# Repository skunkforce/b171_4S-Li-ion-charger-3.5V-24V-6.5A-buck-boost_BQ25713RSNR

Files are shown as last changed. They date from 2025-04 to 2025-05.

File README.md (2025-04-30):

# edgy_board number b171
This design is part of the [edgy board project](https://github.com/skunkforce/edgy_boards).



# getting started
This repository uses submodules. After cloning use the command 

```$ git submodule update --init --recursive```

to pull the submodules before opening the project with kicad. 

# Tests
Tests can be found in [TESTS.md](TESTS.md)

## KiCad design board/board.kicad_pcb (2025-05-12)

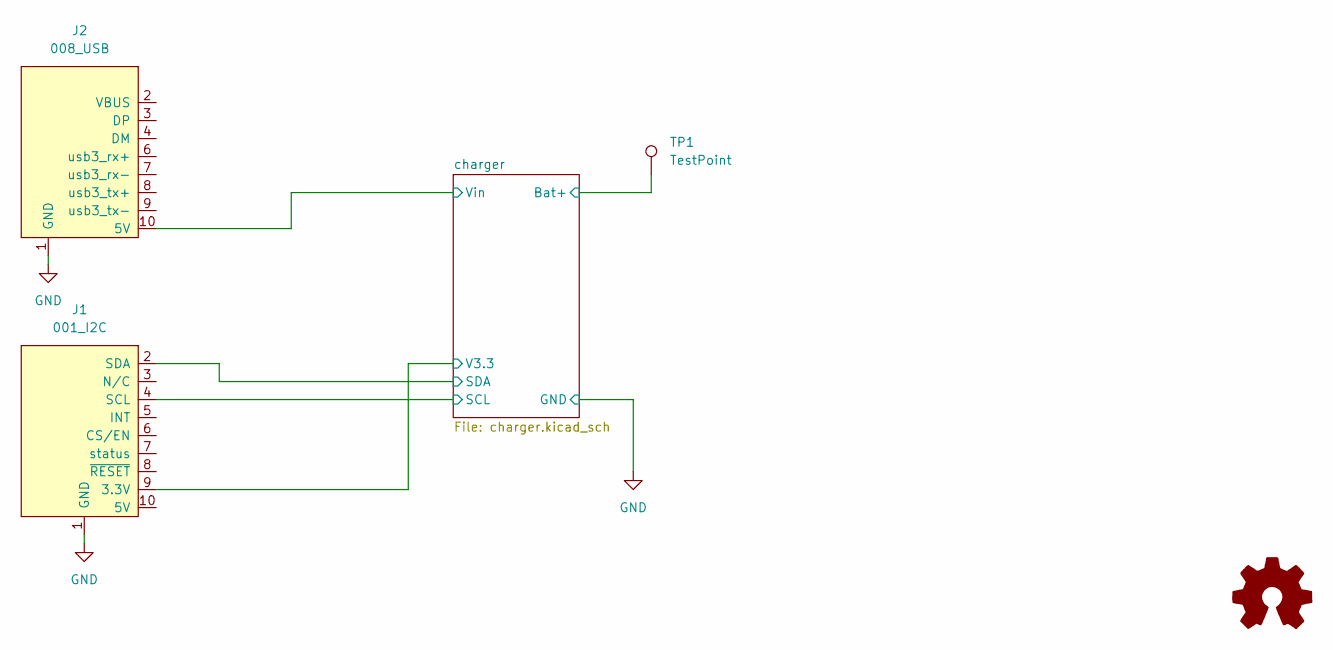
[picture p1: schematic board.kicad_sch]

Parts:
J1: 001_I2C; on_edge_2x05_device
J2: 008_USB; on_edge_2x05_device
LOGO1: Logo_Open_Hardware_Small; OSHW-Symbol_6.7x6mm_SilkScreen
TP1: TestPoint; TestPoint_Loop_D3.80mm_Drill2.8mm

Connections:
/charger/PACK+: TP1.1; also elsewhere on the board
/charger/SCL: J1.4 (SCL); also elsewhere on the board
/charger/SDA: J1.2 (SDA); also elsewhere on the board
/charger/V3.3: J1.9 (3.3V); also elsewhere on the board
/charger/VBUS: J2.10 (5V); also elsewhere on the board
GND: J1.1 (GND), J2.1 (GND); also elsewhere on the board

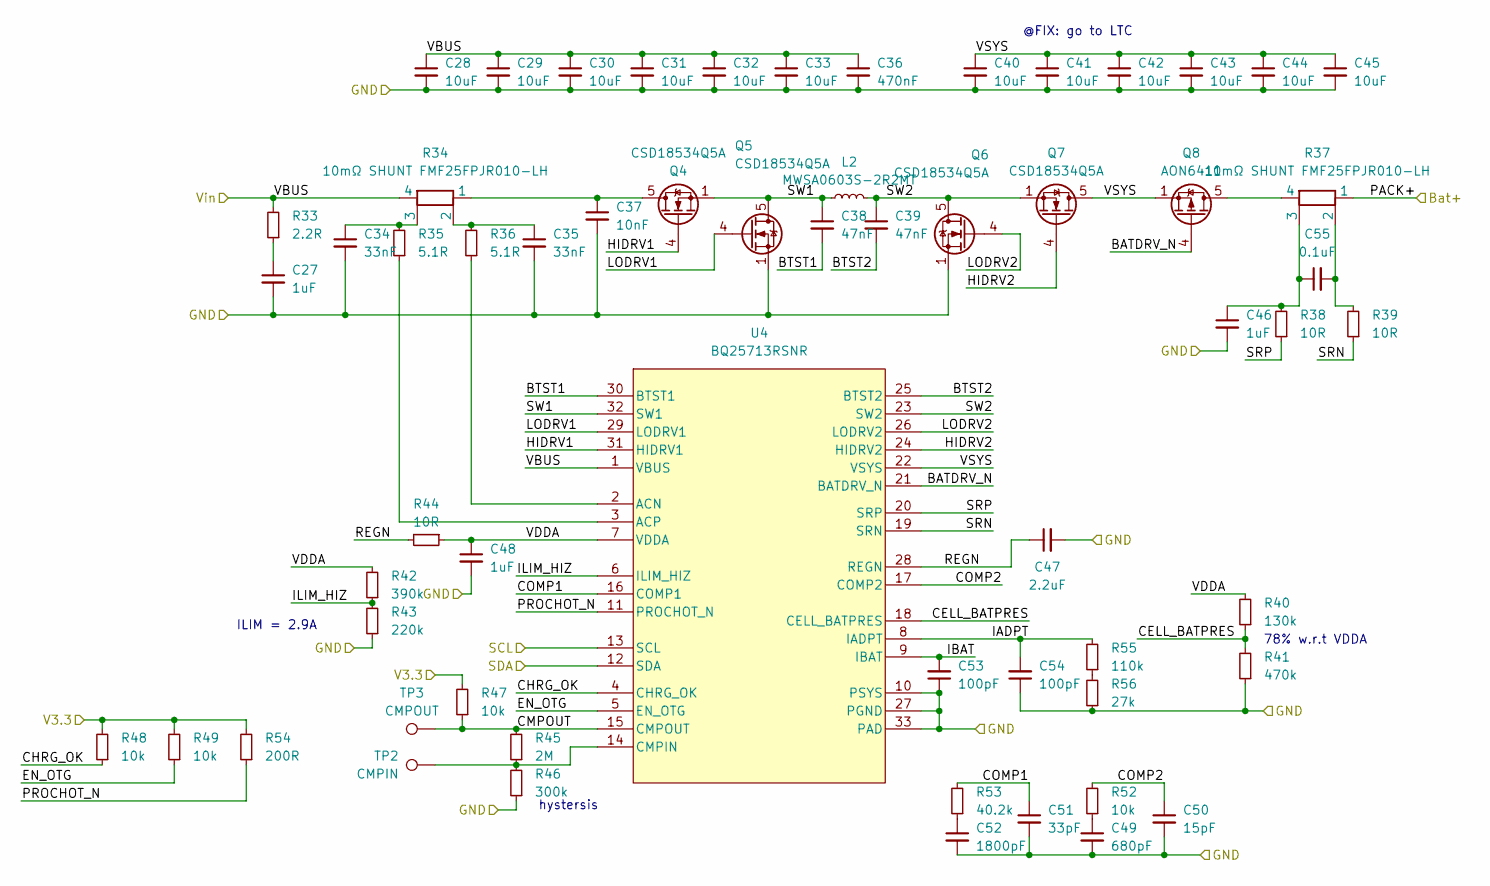
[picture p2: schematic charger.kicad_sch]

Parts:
C27, C46, C48: 1uF; C_0603_1608Metric; LCSC C15849
C28, C29, C30, C31, C32, C33, C40, C41, C42, C43, C44, C45: 10uF; C_0603_1608Metric; LCSC C96446
C34, C35: 33nF; C_0603_1608Metric; LCSC C21117
C36: 470nF; C_0603_1608Metric; LCSC C1623
C37: 10nF; C_0603_1608Metric; LCSC C57112
C38, C39: 47nF; C_0603_1608Metric; LCSC C1622
C47: 2.2uF; C_0603_1608Metric; LCSC C23630
C49: 680pF; C_0603_1608Metric; LCSC C1630
C50: 15pF; C_0603_1608Metric; LCSC C1644
C51: 33pF; C_0603_1608Metric; LCSC C1663
C52: 1800pF; C_0603_1608Metric; LCSC C1599
C53, C54: 100pF; C_0603_1608Metric; LCSC C14858
C55: 0.1uF; C_0603_1608Metric; LCSC C14663
L2: MWSA0603S-2R2MT; L_Sunlord_MWSA0603S; LCSC C408445
Q4, Q5, Q6, Q7: CSD18534Q5A; TDSON-8-1; LCSC C115943
Q8: AON6411; AO_DFN-8-1EP_5.55x5.2mm_P1.27mm_EP4.12x4.6mm
R33: 2.2R; R_0603_1608Metric; LCSC C22939
R34, R37: 10mΩ SHUNT FMF25FPJR010-LH; R_Shunt_Vishay_WSK2512_6332Metric_T1.19mm; LCSC C105366
R35, R36: 5.1R; R_0603_1608Metric; LCSC C25197
R38, R39, R44: 10R; R_0603_1608Metric; LCSC C22859
R40: 130k; R_0603_1608Metric; LCSC C22795
R41: 470k; R_0603_1608Metric; LCSC C23178
R42: 390k; R_0603_1608Metric; LCSC C23150
R43: 220k; R_0603_1608Metric; LCSC C22961
R45: 2M; R_0603_1608Metric; LCSC C22976
R46: 300k; R_0603_1608Metric; LCSC C23024
R47, R48, R49, R52: 10k; R_0603_1608Metric; LCSC C25804
R53: 40.2k; R_0603_1608Metric; LCSC C12447
R54: 200R; R_0603_1608Metric; LCSC C8218
R55: 110k; R_0603_1608Metric; LCSC C25805
R56: 27k; R_0603_1608Metric; LCSC C22967
TP2: CMPIN; TestPoint_Pad_2.0x2.0mm
TP3: CMPOUT; TestPoint_Pad_2.0x2.0mm
U4: BQ25713RSNR; Texas_RSN_WQFN-32-1EP_4x4mm_P0.4mm_EP2.8x2.8mm_ThermalVias; LCSC C2878935

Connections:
/charger/BATDRV_N: Q8.4 (G), U4.21 (BATDRV_N)
/charger/BTST1: C38.2, U4.30 (BTST1)
/charger/BTST2: C39.2, U4.25 (BTST2)
/charger/CELL_BATPRES: R40.1, R41.2, U4.18 (CELL_BATPRES)
/charger/CHRG_OK: R48.1, U4.4 (CHRG_OK)
/charger/CMPOUT: R45.2, R47.1, TP3.1, U4.15 (CMPOUT)
/charger/COMP1: C51.1, R53.2, U4.16 (COMP1)
/charger/COMP2: C50.1, R52.2, U4.17 (COMP2)
/charger/EN_OTG: R49.1, U4.5 (EN_OTG)
/charger/HIDRV1: Q4.4 (G), U4.31 (HIDRV1)
/charger/HIDRV2: Q7.4 (G), U4.24 (HIDRV2)
/charger/IADPT: C54.2, R55.2, U4.8 (IADPT)
/charger/IBAT: C53.2, U4.9 (IBAT)
/charger/ILIM_HIZ: R42.1, R43.2, U4.6 (ILIM_HIZ)
/charger/LODRV1: Q5.4 (G), U4.29 (LODRV1)
/charger/LODRV2: Q6.4 (G), U4.26 (LODRV2)
/charger/PACK+: R37.1; also elsewhere on the board
/charger/PROCHOT_N: R54.1, U4.11 (PROCHOT_N)
/charger/REGN: C47.1, R44.2, U4.28 (REGN)
/charger/SCL: U4.13 (SCL); also elsewhere on the board
/charger/SDA: U4.12 (SDA); also elsewhere on the board
/charger/SRN: R39.1, U4.19 (SRN)
/charger/SRP: R38.1, U4.20 (SRP)
/charger/SW1: C38.1, L2.1, Q4.1 (S), Q4.2 (S), Q4.3 (S), Q5.5 (D), U4.32 (SW1)
/charger/SW2: C39.1, L2.2, Q6.5 (D), Q7.1 (S), Q7.2 (S), Q7.3 (S), U4.23 (SW2)
/charger/V3.3: R47.2, R48.2, R49.2, R54.2; also elsewhere on the board
/charger/VBUS: C28.1, C29.1, C30.1, C31.1, C32.1, C33.1, C36.1, R33.2, R34.4, U4.1 (VBUS); also elsewhere on the board
/charger/VDDA: C48.1, R40.2, R42.2, R44.1, U4.7 (VDDA)
/charger/VSYS: C40.1, C41.1, C42.1, C43.1, C44.1, C45.1, Q7.5 (D), Q8.1 (S), Q8.2 (S), Q8.3 (S), U4.22 (VSYS)
GND: C27.2, C28.2, C29.2, C30.2, C31.2, C32.2, C33.2, C34.2, C35.2, C36.2, C37.2, C40.2, C41.2, C42.2, C43.2, C44.2, C45.2, C46.2, C47.2, C48.2, C49.2, C50.2, C51.2, C52.2, C53.1, C54.1, Q5.1 (S), Q5.2 (S), Q5.3 (S), Q6.1 (S), Q6.2 (S), Q6.3 (S), R41.1, R43.1, R46.1, R56.1, U4.10 (PSYS), U4.27 (PGND), U4.33 (PAD); also elsewhere on the board
unnamed: C27.1, R33.1
unnamed: C34.1, R34.3, R35.2
unnamed: C35.1, R34.2, R36.2
unnamed: C46.1, C55.1, R37.3, R38.2
unnamed: C49.1, R52.1
unnamed: C52.1, R53.1
unnamed: C55.2, R37.2, R39.2
unnamed: C37.1, Q4.5 (D), R34.1
unnamed: Q8.5 (D), R37.4
unnamed: R55.1, R56.2
unnamed: R36.1, U4.2 (ACN)
unnamed: R35.1, U4.3 (ACP)
unnamed: R45.1, R46.2, TP2.1, U4.14 (CMPIN)

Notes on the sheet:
@FIX: go to LTC
ILIM = 2.9A
hystersis
78% w.r.t VDDA

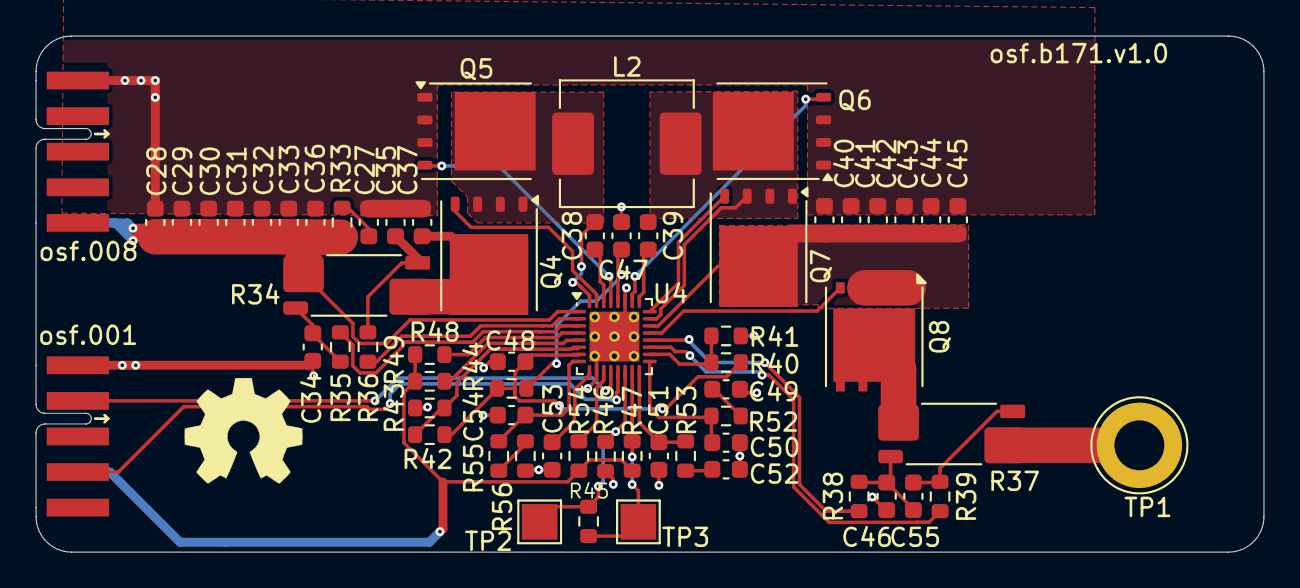
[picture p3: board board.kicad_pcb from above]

Board: 2 copper layers, 69.0 x 29.0 mm, 64 parts (0 on the bottom side), 43 nets.
